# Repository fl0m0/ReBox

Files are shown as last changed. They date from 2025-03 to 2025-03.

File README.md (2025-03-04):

# ReBox - Programmable Relay Switch Box

I started this project to overcome a few nuisances at my working place. I use a couple of old bench power supplies that are still fine. But every one of those suckers features only a mains power switch. So if you hit this switch, the power supply makes a (surprisingly satisfying) 'brrroomp' sound and all output voltage rails go live. The resulting switching transients are neither particularly nice nor repeatable. Nothing you want to hook up to some electronic device.

Yeah, you can solve this by a simple cable switch, what I did. But then, what to do when you need to switch two supply voltages at the same time? You build another cable switch with a double pole single (DPST) throw switch. And if you've got three supply voltages? Well, this is were this projects starts.

My goals for this new device (unimaginatively called ReBox) to be developed were:

* Capability to switch up to six voltages
* Maximum switching current of 10 A at 30 V per channel
* Relays for switching
* 4 mm banana jacks for in- and outputs
* Programmable switch groups: switches in the same group will switch at the same time instance
* Power is supplied via USB-C connector (increasingly common, much more robust than Micro-USB)
* USB-serial interface for debugging and remote control
* Some fancy RGB-LED stuff

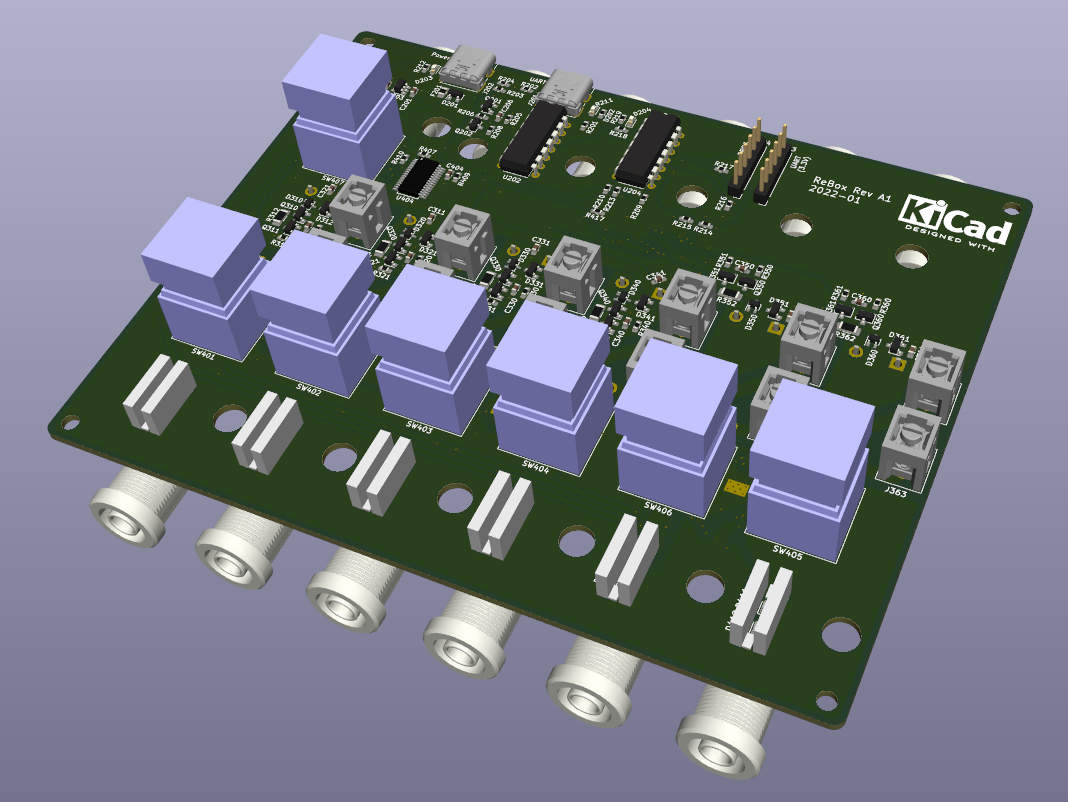
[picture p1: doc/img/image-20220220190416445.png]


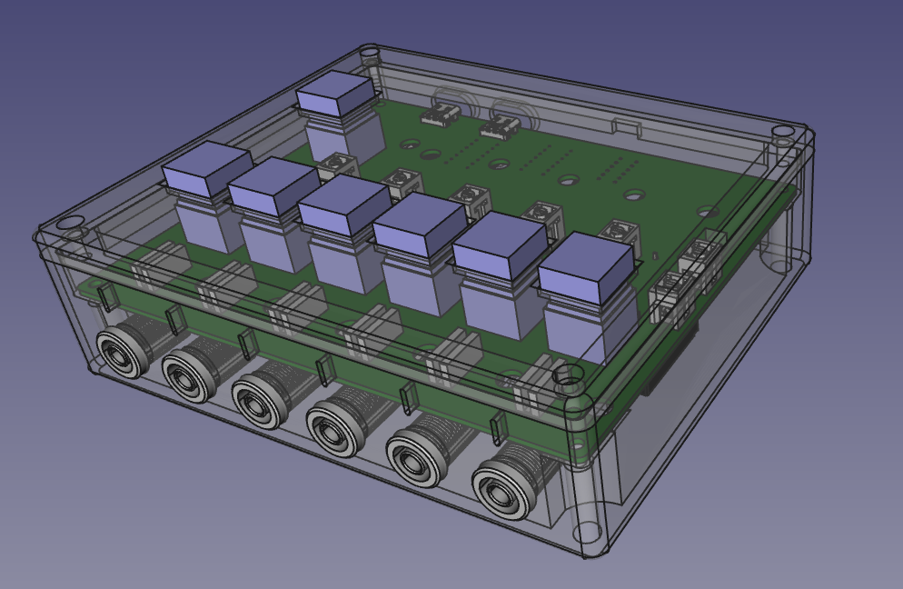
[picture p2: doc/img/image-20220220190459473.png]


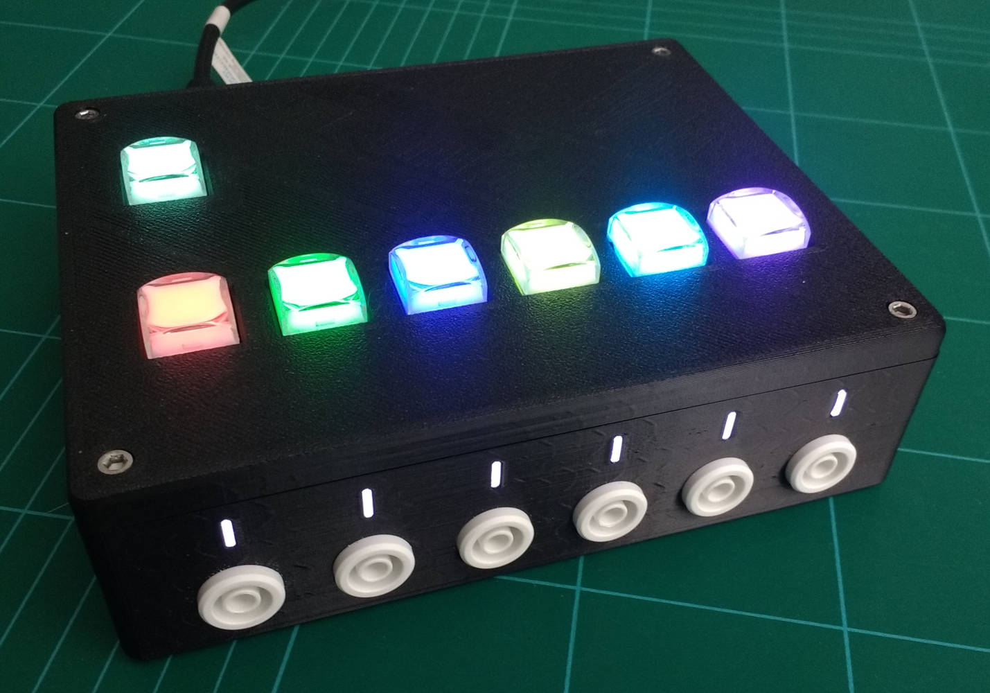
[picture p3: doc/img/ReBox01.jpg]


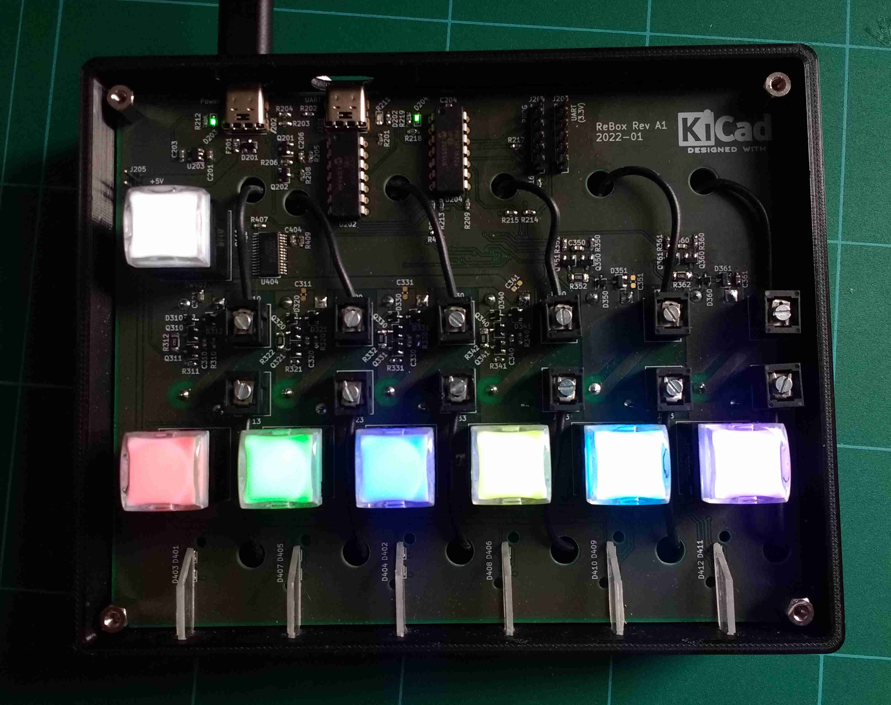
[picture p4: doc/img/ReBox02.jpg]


# Component Choices

## Push Buttons

After intensive searching I went for push buttons I found on AliExpress: [PB06-B-WT-2RGB-N-Y](http://www.honyone.com/en/products/list_32_1.html). They were in stock, cheap an looked quite nice. The downside: they lacked in the documentation department. Those are push buttons with RGB LEDs. Perfect for assigning each push button to a group / color.

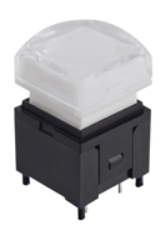
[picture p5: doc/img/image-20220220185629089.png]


## MCU

I was already familiar with the Microchip PIC MCUs. So I chose a PIC16. I have only a PICKit 3 Programmer that doesn't feature an integrated UART for debugging. So some kind of external UART is nescessary.

## USB UART

I went for a [MCP2221A](https://www.microchip.com/en-us/product/MCP2221A) as a USB to UART converter after I realized that none of usual FTDI chips were in stock. I also had to go with a big DIP package (same for the MCU).

```mermaid
stateDiagram-v2
state "SYSTEM_Initialize()" as system_init
state "Init IO expander<br>IO config, all realys off" as init_io_ctrl
state "Init LED controllers,<br>all LEDs off" as init_led_ctrl
state "Get push button states" as get_pb_states
 [*] --> init
 state init {
 	[*] --> system_init
 	system_init --> init_io_ctrl
 	init_io_ctrl --> init_led_ctrl
 	init_led_ctrl --> [*]
 }
 init --> super_loop
 state super_loop {
 get_pb_states --> two
 }
 super_loop --> super_loop: tmr0_trigger = 1

```

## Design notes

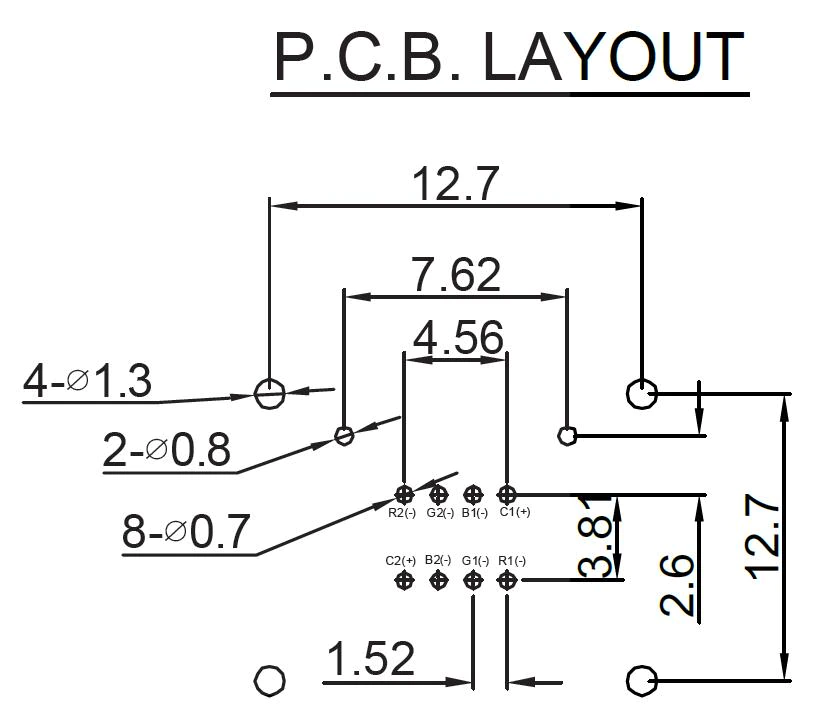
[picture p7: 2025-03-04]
doc/datasheets/switch/Hdd3ee6b0d6b543dcbb89db70b7351162p.webp

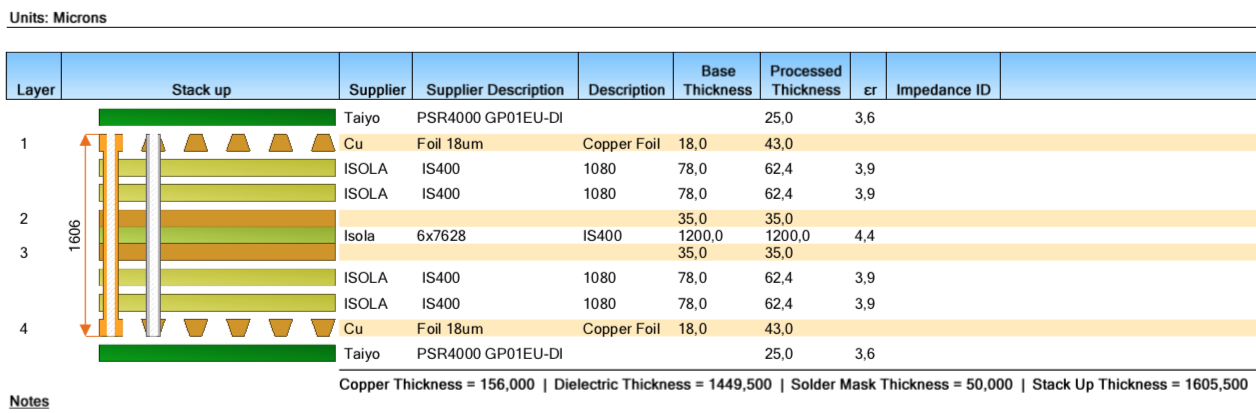
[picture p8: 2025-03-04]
doc/datasheets/PCB/4-layerstackup-275ac8cc.png

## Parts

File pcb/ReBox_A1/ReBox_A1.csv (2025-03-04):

Bestellstatus | Reference | Quantity | Value | Footprint | Datasheet | Manufacturer | SPN | Supplier | Info | Pretty Value | Pretty Value 1 | Pretty Value 2 | Supplier Part Number | DNP | Supplier 1 | Prettl Value
Vorhanden | C201 C205 C401 C402 C403 C404 | 6 | 100nF,50V,X7R,0603 | Capacitor_SMD:C_0603_1608Metric_Pad1.08x0.95mm_HandSolder | ~ |  |  |  |  |  | 100nF, 50V | X7R, 0603
Ersatz 1UF 35V X7R 0603 | C202 C203 | 2 | 1uF,16V,X7R,0603 | Capacitor_SMD:C_0603_1608Metric_Pad1.08x0.95mm_HandSolder | ~ |  |  |  |  |  | 1μF, 16V | X7R, 0603
Ersatz CC0603KRX7R8BB474 | C204 C301 C302 C303 C304 C305 C306 | 7 | 470nF,50V,X7R,0805 | Capacitor_SMD:C_0805_2012Metric_Pad1.18x1.45mm_HandSolder | ~ |  |  |  |  |  | 470nF, 50V | X7R, 0805
OK | D201 | 1 | 824021 | Package_TO_SOT_SMD_User:SOT-23_Handsoldering | https://www.we-online.com/catalog/datasheet/824021.pdf | Wurth Elektronik | 732-4468-1-ND | Digi-Key
Ersatz LTST-C191TGKT | D202 D203 D204 | 3 | 150060GS75000 | LED_SMD:LED_0603_1608Metric_Pad1.05x0.95mm_HandSolder | https://www.we-online.com/katalog/datasheet/150060GS75000.pdf | Wurth Elektronik | 732-4971-1-ND | Digi-Key | Green
OK | D302 D304 D306 D308 D310 D312 | 6 | BZX84C12-7-F | Diode_SMD_User:D_SOT-23_ANK_Handsoldering | https://www.diodes.com/assets/Datasheets/ds18001.pdf | Diodes Incorporated | BZX84C12-FDICT-ND | Digi-Key
OK | D301 D303 D305 D307 D309 D311 | 6 | BAT54W,xxx | Package_TO_SOT_SMD_User:SOT-323_SC-70_Handsoldering | https://assets.nexperia.com/documents/data-sheet/BAT54W_SER.pdf | Nexperia | 1727-3570-1-ND | Digi-Key
OK | D401 D402 D403 D404 D405 D406 D407 D408 D409 D410 D411 D412 | 12 | IN-S63AT5UW | LED_SMD_User:LED_0603_1608Metric_Low_Profile | http://www.inolux-corp.com/datasheet/SMDLED/Mono%20Color%20Top%20View/IN-S63AT%20Series_V1.1.pdf | Inolux | 1830-1063-1-ND | Digi-Key | White
OK | F201 | 1 | 0805L110SLxx | Fuse:Fuse_0805_2012Metric_Pad1.15x1.40mm_HandSolder | https://www.littelfuse.com/media?itemid=2d55f293-08b4-4e1c-af6d-dbdeccdec69c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 | Littelfuse | F3365CT-ND | Digi-Key | 1.1 A, 6V |  |  |  | F3365CT-ND
OK | J201 J202 | 2 | 2137160001 | Connector_User:USB_C_Receptacle_Molex_2137160001 | https://www.molex.com/molex/products/part-detail/io_connectors/2137160001 | Molex | 900-2137160001CT-ND | Digi-Key
OK | J203 J204 | 2 | 77311-118-06LF | Connector_PinHeader_2.54mm:PinHeader_1x06_P2.54mm_Vertical | https://cdn.amphenol-icc.com/media/wysiwyg/files/drawing/77311.pdf | Amphenol | 609-5682-ND | Digi-Key |  |  |  |  |  | DNP
Evtl. Vertikal? | J301 J302 J303 J304 J305 J306 J307 J308 J309 J310 J311 J312 | 12 | 928814-1 | Connector_User:TE_928814-1_PCB_Tab_Quick_Disconnect_4.75x0.81mm_P5.08mm_Horizontal | https://www.te.com/commerce/DocumentDelivery/DDEController?Action=showdoc | TE | A106570-ND | Digi-Key | PCB Tab
Ersatz BSS138AKA | Q201 Q202 | 2 | BSS138BK | Package_TO_SOT_SMD_User:SOT-23_Handsoldering | https://assets.nexperia.com/documents/data-sheet/BSS138BK.pdf | Nexperia | 1727-1141-1-ND | Digi-Key
OK | Q301 Q302 Q303 Q304 Q305 Q306 Q307 Q308 Q309 Q310 Q311 Q312 | 12 | BSH103,xxx | Package_TO_SOT_SMD_User:SOT-23_HandSoldering | https://assets.nexperia.com/documents/data-sheet/BSH103.pdf | Nexperia | 1727-4319-1-ND | Digi-Key
Vorhanden | R202 R203 R217 R218 R219 | 5 | 2.2k,0603 | Resistor_SMD:R_0603_1608Metric_Pad1.05x0.95mm_HandSolder | ~ |  |  |  | 1%, 0,1W | 2.2k, 0603
Vorhanden | R201 R204 R205 R206 R207 R212 R215 R301 R306 R311 R312 R317 R318 R401 R402 R405 R407 | 17 | 10k,0603 | Resistor_SMD:R_0603_1608Metric_Pad1.05x0.95mm_HandSolder | ~ |  |  |  | 1%, 0,1W | 10k, 0603
OK | R208 R209 R214 R216 | 4 | 5.1k,0603 | Resistor_SMD:R_0603_1608Metric_Pad1.05x0.95mm_HandSolder | ~ |  |  |  | 1%, 0,1W | 5.1k, 0603
Vorhanden | R210 R211 | 2 | 0R,0603 | Resistor_SMD:R_0603_1608Metric_Pad1.05x0.95mm_HandSolder | ~ |  |  |  |  |  | 0R, 0603 | 1%, 0,1W
Vorhanden | R213 | 1 | 0R,0603 | Resistor_SMD:R_0603_1608Metric_Pad0.98x0.95mm_HandSolder | ~ |  |  |  |  |  | 0R, 0603 | 1%, 0,1W |  | DNP
OK | R302 R303 R307 R308 R313 R314 | 6 | 330k,0603 | Resistor_SMD:R_0603_1608Metric_Pad1.05x0.95mm_HandSolder | ~ |  |  |  | 1%, 0,1W | 330k, 0603
OK | R304 R305 R309 R310 R315 R316 | 6 | 47R,1206 | Resistor_SMD:R_1206_3216Metric_Pad1.42x1.75mm_HandSolder | ~ |  |  |  | 1%, 0,5W | 47R, 1206
OK | R403 R404 R406 R408 | 4 | 3k,0603 | Resistor_SMD:R_0603_1608Metric_Pad1.05x0.95mm_HandSolder | ~ |  |  |  | 1%, 0,1W | 3k, 0603
Vorhanden | R409 R410 | 2 | 100k,0603 | Resistor_SMD:R_0603_1608Metric_Pad0.98x0.95mm_HandSolder | ~ |  |  |  |  |  | 100k, 0603 | 1%, 0,1W
OK | RL301 RL302 RL303 RL304 RL305 RL306 | 6 | JW1aFSN-DC5V-F | Relay_THT:Relay_SPST_Panasonic_JW1_FormA | http://www3.panasonic.biz/ac/e_download/control/relay/power/catalog/mech_eng_jw.pdf?via=ok | Panasonic | 255-3442-ND |  |  |  |  |  |  |  | Digi-Key
OK | SW401 SW402 SW403 SW404 SW405 SW406 SW407 | 7 | PB06-B-WT-2RGB-N-Y | Switch_User:PB06-B-Wx-2RGB-x-x | http://www.honyone.com/en/products/show_243.html | HONYONNE
OK | U201 | 1 | PCA9535DWR | Package_SO:SOIC-24W_7.5x15.4mm_P1.27mm | https://www.ti.com/lit/ds/symlink/pca9535.pdf | Texas Instruments | 296-20950-1-ND | Digi-Key
Ersatz PIC16F18326-I/P | U202 | 1 | PIC16F18326-ISL | Package_SO:SOIC-14_3.9x8.7mm_P1.27mm | https://ww1.microchip.com/downloads/en/DeviceDoc/40001839E.pdf |  | PIC16F18326-I/SL-ND | Digi-Key
Vorhanden | U203 | 1 | XC6210B332MR | Package_TO_SOT_SMD:SOT-23-5 | https://www.torexsemi.com/file/xc6210/XC6210.pdf
OK | U204 | 1 | MCP2221AxP | Package_DIP:DIP-14_W7.62mm | http://ww1.microchip.com/downloads/en/DeviceDoc/20005565B.pdf | Microchip | MCP2221A-I/P-ND | Digi-Key
OK | U205 | 1 | 824001 | Package_TO_SOT_SMD:SOT-23-6_Handsoldering | https://www.we-online.com/catalog/datasheet/824001.pdf | Wuerth Elektronik | 732-4464-1-ND | Digi-Key
OK | U401 U402 U403 U404 | 4 | PCA9955TW | Package_SO_User:HTSSOP28_EP | https://www.nxp.com/docs/en/data-sheet/PCA9955B.pdf | NXP | 568-12427-1-ND | Digi-Key

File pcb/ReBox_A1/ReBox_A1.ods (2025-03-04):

Bestellstatus | Reference | Quantity | Value | Manufacturer | SPN | Supplier | Info | Pretty Value | Pretty Value 1 | Pretty Value 2 | Supplier Part Number | DNP | Supplier 1 | Prettl Value
Vorhanden | C201 C205 C401 C402 C403 C404 | 6 | 100nF,50V,X7R,0603 |  |  |  |  |  | 100nF, 50V | X7R, 0603
Ersatz 1UF 35V X7R 0603 | C202 C203 | 2 | 1uF,16V,X7R,0603 |  |  |  |  |  | 1μF, 16V | X7R, 0603
Ersatz CC0603KRX7R8BB474 | C204 C301 C302 C303 C304 C305 C306 | 7 | 470nF,50V,X7R,0805 |  |  |  |  |  | 470nF, 50V | X7R, 0805
OK | D201 | 1 | 824021 | Wurth Elektronik | 732-4468-1-ND | Digi-Key
Ersatz LTST-C191TGKT | D202 D203 D204 | 3 | 150060GS75000 | Wurth Elektronik | 732-4971-1-ND | Digi-Key | Green
OK | D302 D304 D306 D308 D310 D312 | 6 | BZX84C12-7-F | Diodes Incorporated | BZX84C12-FDICT-ND | Digi-Key
OK | D301 D303 D305 D307 D309 D311 | 6 | BAT54W,xxx | Nexperia | 1727-3570-1-ND | Digi-Key
OK | D401 D402 D403 D404 D405 D406 D407 D408 D409 D410 D411 D412 | 12 | IN-S63AT5UW | Inolux | 1830-1063-1-ND | Digi-Key | White
OK | F201 | 1 | 0805L110SLxx | Littelfuse | F3365CT-ND | Digi-Key | 1.1 A, 6V |  |  |  | F3365CT-ND
OK | J201 J202 | 2 | 2137160001 | Molex | 900-2137160001CT-ND | Digi-Key
OK | J203 J204 | 2 | 77311-118-06LF | Amphenol | 609-5682-ND | Digi-Key |  |  |  |  |  | DNP
Entfällt | J301 J302 J303 J304 J305 J306 J307 J308 J309 J310 J311 J312 | 12 | 928814-1 | TE | A106570-ND | Digi-Key | PCB Tab
Ersatz BSS138AKA | Q201 Q202 | 2 | BSS138BK | Nexperia | 1727-1141-1-ND | Digi-Key
OK | Q301 Q302 Q303 Q304 Q305 Q306 Q307 Q308 Q309 Q310 Q311 Q312 | 12 | BSH103,xxx | Nexperia | 1727-4319-1-ND | Digi-Key
Vorhanden | R202 R203 R217 R218 R219 | 5 | 2.2k,0603 |  |  |  | 1%, 0,1W | 2.2k, 0603
Vorhanden | R201 R204 R205 R206 R207 R212 R215 R301 R306 R311 R312 R317 R318 R401 R402 R405 R407 | 17 | 10k,0603 |  |  |  | 1%, 0,1W | 10k, 0603
OK | R208 R209 R214 R216 | 4 | 5.1k,0603 |  |  |  | 1%, 0,1W | 5.1k, 0603
Vorhanden | R210 R211 | 2 | 0R,0603 |  |  |  |  |  | 0R, 0603 | 1%, 0,1W
Vorhanden | R213 | 1 | 0R,0603 |  |  |  |  |  | 0R, 0603 | 1%, 0,1W |  | DNP
OK | R302 R303 R307 R308 R313 R314 | 6 | 330k,0603 |  |  |  | 1%, 0,1W | 330k, 0603
OK | R304 R305 R309 R310 R315 R316 | 6 | 47R,1206 |  |  |  | 1%, 0,5W | 47R, 1206
OK | R403 R404 R406 R408 | 4 | 3k,0603 |  |  |  | 1%, 0,1W | 3k, 0603
Vorhanden | R409 R410 | 2 | 100k,0603 |  |  |  |  |  | 100k, 0603 | 1%, 0,1W
OK | RL301 RL302 RL303 RL304 RL305 RL306 | 6 | JW1aFSN-DC5V-F | Panasonic | 255-3442-ND |  |  |  |  |  |  |  | Digi-Key
OK | SW401 SW402 SW403 SW404 SW405 SW406 SW407 | 7 | PB06-B-WT-2RGB-N-Y | HONYONNE
OK | U201 | 1 | PCA9535DWR | Texas Instruments | 296-20950-1-ND | Digi-Key
Ersatz PIC16F18326-I/P | U202 | 1 | PIC16F18326-ISL |  | PIC16F18326-I/SL-ND | Digi-Key
Vorhanden | U203 | 1 | XC6210B332MR
OK | U204 | 1 | MCP2221AxP | Microchip | MCP2221A-I/P-ND | Digi-Key
OK | U205 | 1 | 824001 | Wuerth Elektronik | 732-4464-1-ND | Digi-Key
OK | U401 U402 U403 U404 | 4 | PCA9955TW | NXP | 568-12427-1-ND | Digi-Key

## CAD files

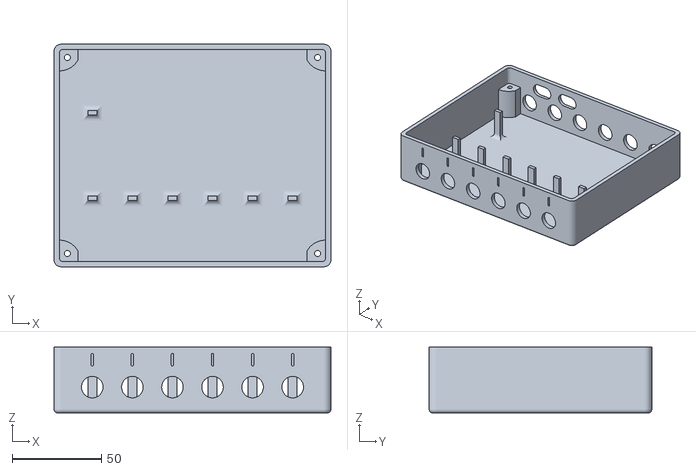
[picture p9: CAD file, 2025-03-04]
mechanical/case_base.stl
155.5 x 125.0 x 37.0

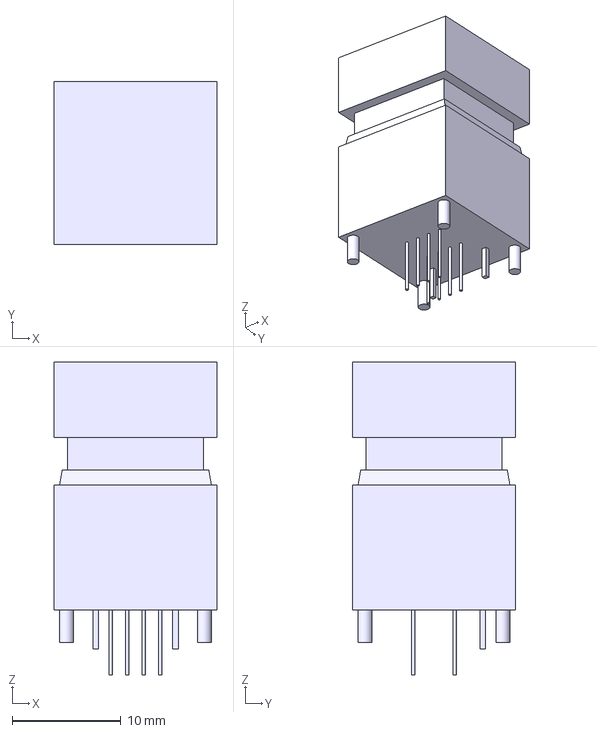
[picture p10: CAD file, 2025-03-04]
mechanical/PB06-B-Wx-2RGB-x-x.step
15.0 x 15.0 x 28.9 mm

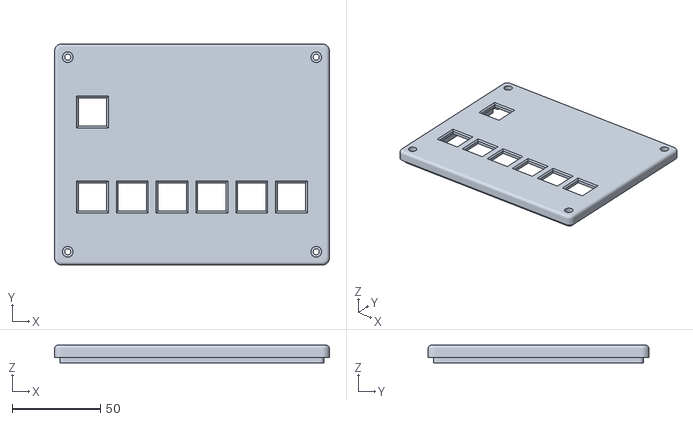
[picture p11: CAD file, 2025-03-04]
mechanical/case_lid.stl
155.5 x 125.0 x 10.0

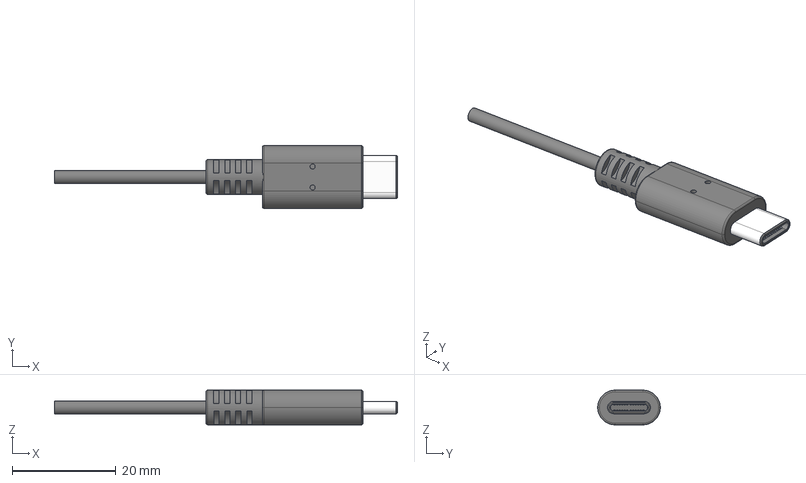
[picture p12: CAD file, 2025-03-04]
mechanical/Official Pi 4 USB-C charger plug.step
66.2 x 12.1 x 6.70 mm
USB Plug
Inner
Outer

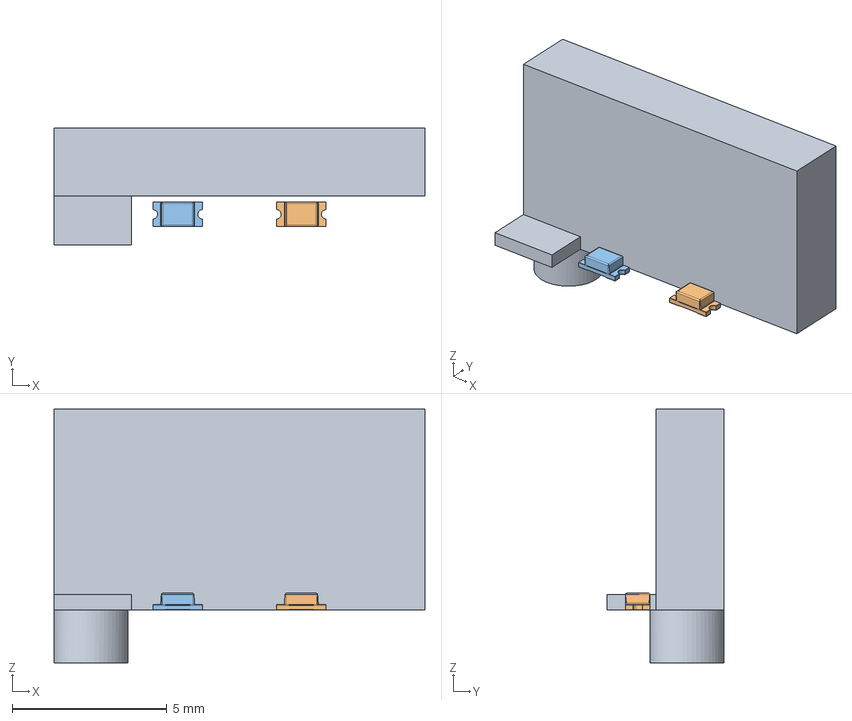
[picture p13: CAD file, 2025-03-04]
mechanical/Light_Pipe_Mount.FCStd
12.0 x 3.80 x 8.20 mm
LED1
LED2

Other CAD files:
mechanical/AI3M_case_base.3mf
mechanical/AI3M_case_lid.3mf
mechanical/Light_Pipe_Mount.stl
mechanical/PB06-B-Wx-2RGB-x-x.FCStd

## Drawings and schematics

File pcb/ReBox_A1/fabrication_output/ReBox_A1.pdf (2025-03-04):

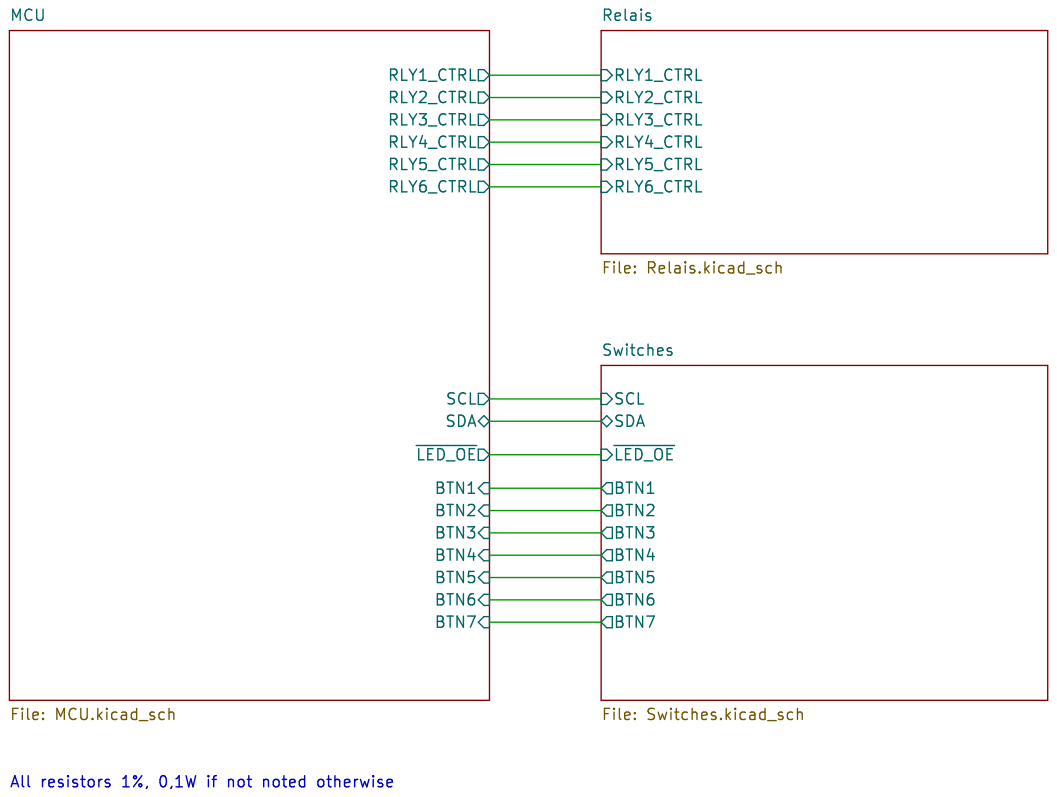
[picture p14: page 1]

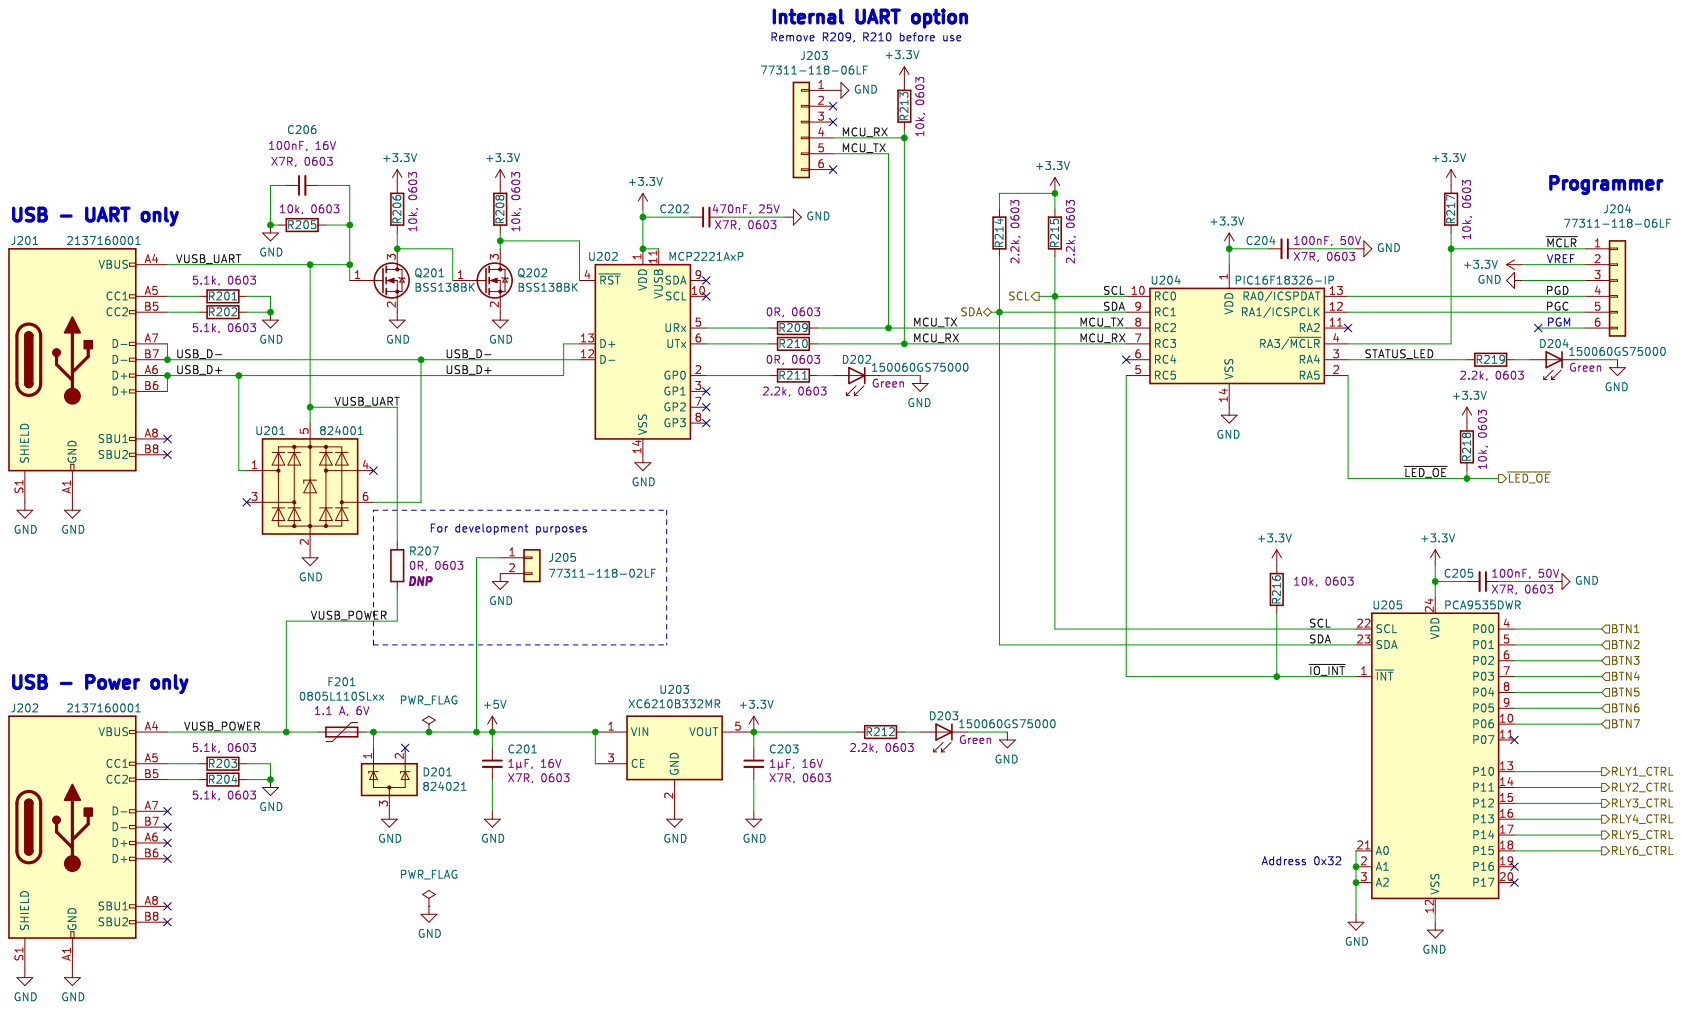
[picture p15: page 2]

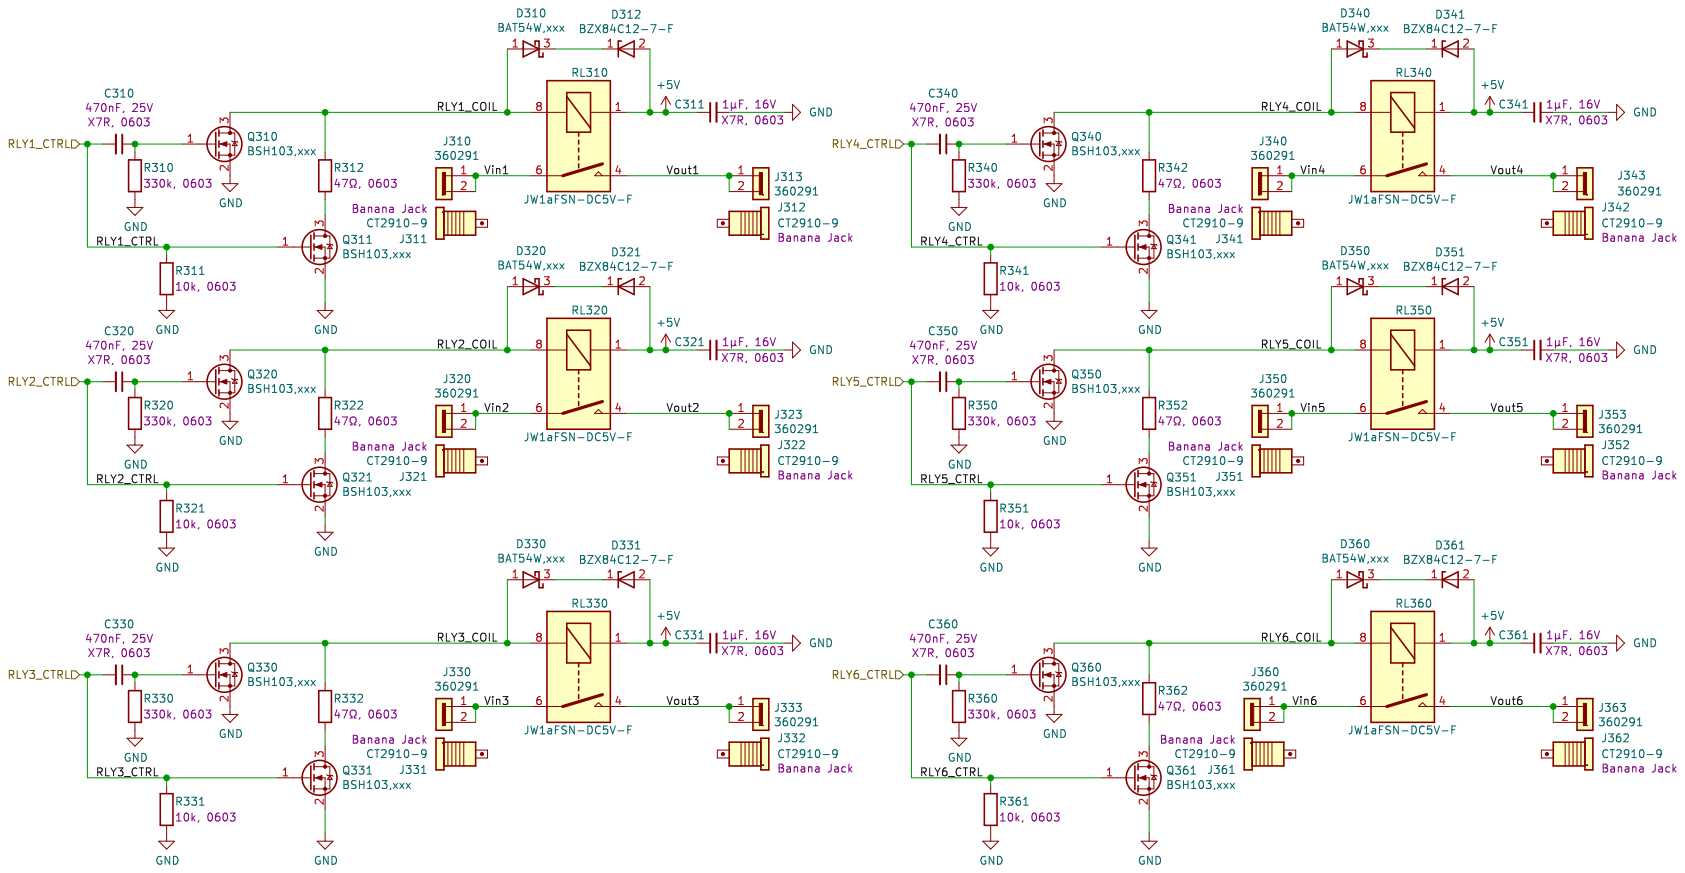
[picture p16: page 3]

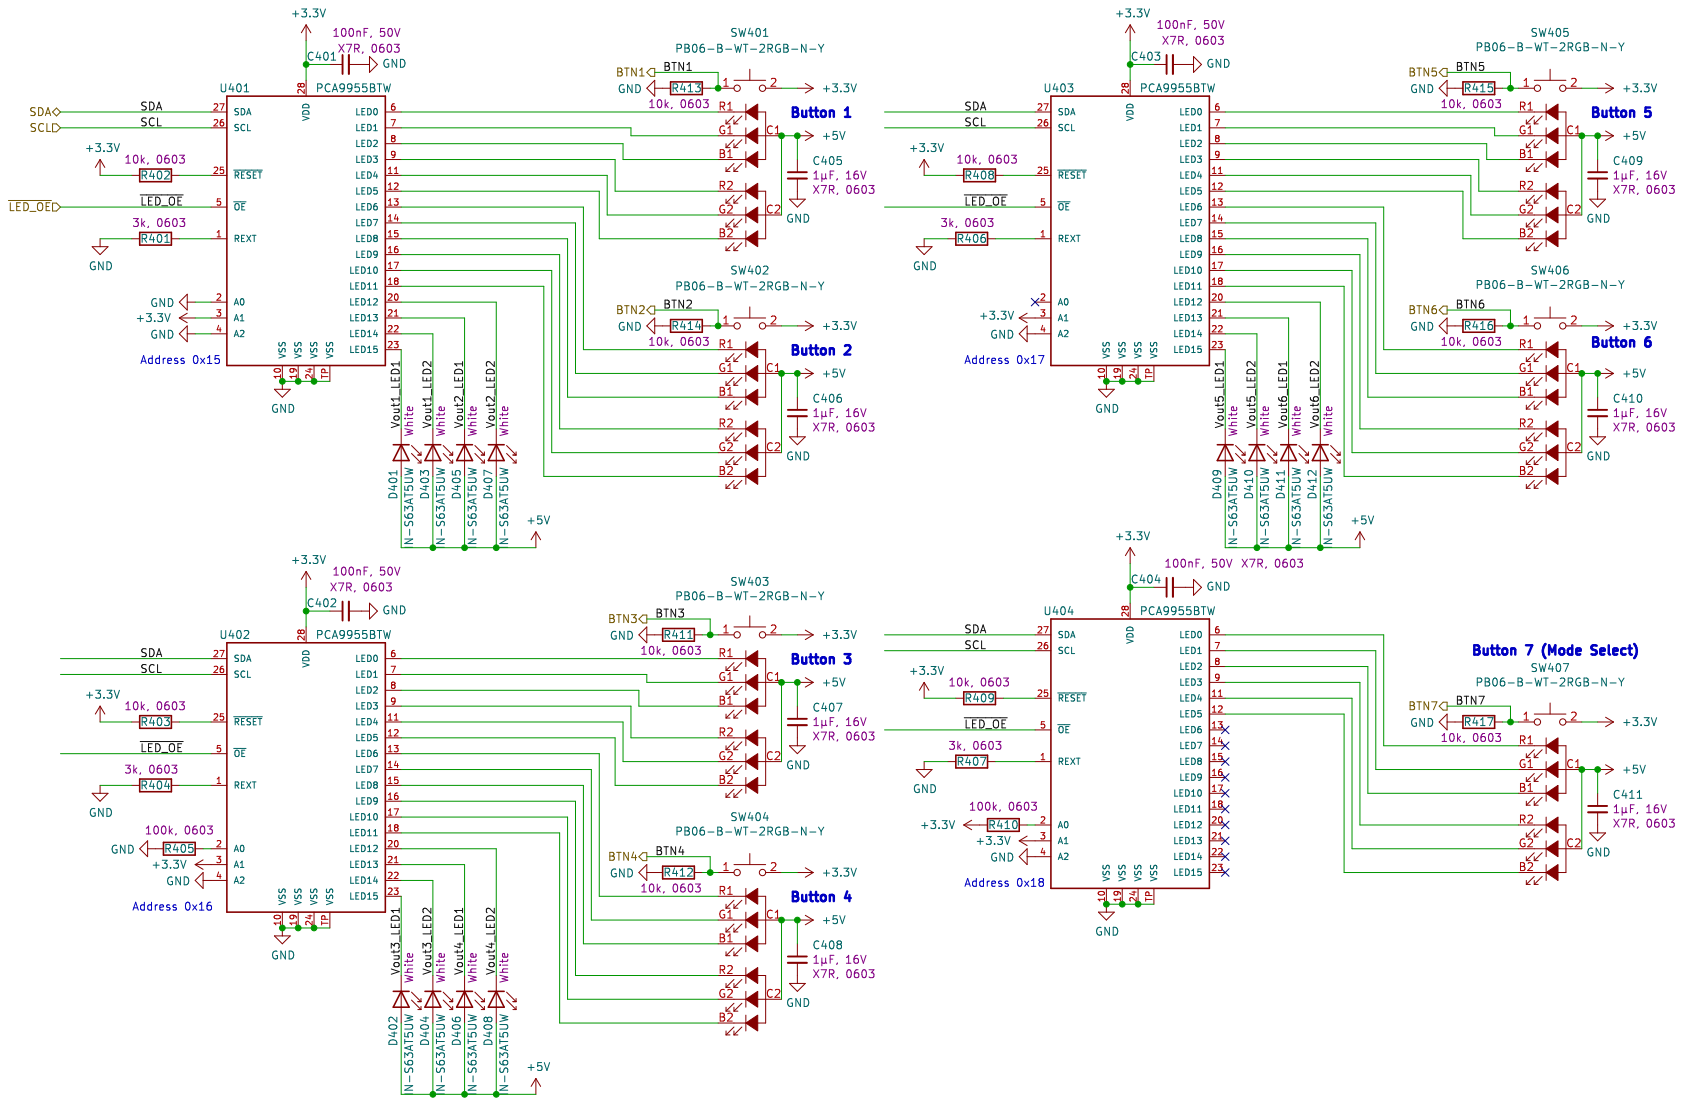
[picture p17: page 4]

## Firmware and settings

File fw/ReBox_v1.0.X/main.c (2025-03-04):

/**
  Generated Main Source File

  Company:
    Microchip Technology Inc.

  File Name:
    main.c

  Summary:
    This is the main file generated using PIC10 / PIC12 / PIC16 / PIC18 MCUs

  Description:
    This header file provides implementations for driver APIs for all modules selected in the GUI.
    Generation Information :
        Product Revision  :  PIC10 / PIC12 / PIC16 / PIC18 MCUs - 1.81.7
        Device            :  PIC16F18326
        Driver Version    :  2.00
*/

/*
    (c) 2018 Microchip Technology Inc. and its subsidiaries. 
    
    Subject to your compliance with these terms, you may use Microchip software and any 
    derivatives exclusively with Microchip products. It is your responsibility to comply with third party 
    license terms applicable to your use of third party software (including open source software) that 
    may accompany Microchip software.
    
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
    IN NO EVENT WILL MICROCHIP BE LIABLE FOR ANY INDIRECT, SPECIAL, PUNITIVE, 
    INCIDENTAL OR CONSEQUENTIAL LOSS, DAMAGE, COST OR EXPENSE OF ANY KIND 
    WHATSOEVER RELATED TO THE SOFTWARE, HOWEVER CAUSED, EVEN IF MICROCHIP 
    HAS BEEN ADVISED OF THE POSSIBILITY OR THE DAMAGES ARE FORESEEABLE. TO 
    THE FULLEST EXTENT ALLOWED BY LAW, MICROCHIP'S TOTAL LIABILITY ON ALL 
    CLAIMS IN ANY WAY RELATED TO THIS SOFTWARE WILL NOT EXCEED THE AMOUNT 
    OF FEES, IF ANY, THAT YOU HAVE PAID DIRECTLY TO MICROCHIP FOR THIS 
    SOFTWARE.
*/

#include "mcc_generated_files/mcc.h"
#include "rebox.h"
#include "i2c.h"
#include "mcc_generated_files/examples/i2c1_master_example.h"

// Global variables
// Color definitions
uint8_t COLOR_RED[3]    = {0xC0,0x00,0x00};
uint8_t COLOR_GREEN[3]  = {0x00,0x80,0x00};
uint8_t COLOR_BLUE[3]   = {0x00,0x00,0xFF};
uint8_t COLOR_YELLOW[3] = {0xD0,0x80,0x00};
uint8_t COLOR_CYAN[3]   = {0x00,0xC0,0xFF};
uint8_t COLOR_VIOLET[3] = {0xC0,0x00,0xFF};
uint8_t COLOR_WHITE[3]  = {0xFF,0x60,0x40};
uint8_t COLOR_OFF[3]    = {0x00,0x00,0x00};
uint8_t COLORS[21]      = {0xC0,0x00,0x00,  // red
                           0x00,0x80,0x00,  // green
                           0x00,0x00,0xFF,  // blue
                           0xD0,0x80,0x00,  // yellow
                           0x00,0xC0,0xFF,  // cyan
                           0xC0,0x00,0xFF,  // violet
                           0xFF,0x60,0x40}; // white

// Timer0: Used for detection of long (2 s) push button presses and some other
//         time delays.
// Timer2: Used for Super Loop, sets tmr0_trigger, 64 ms


/*
                         Main application
 */
void main(void)
{
    operating_mode_t operating_mode = STARTUP;
    // I2C dadresses
    i2c1_address_t led_ctrl0_addr = LED_CTRL0_ADDR;
    i2c1_address_t led_ctrl1_addr = LED_CTRL1_ADDR;
    i2c1_address_t led_ctrl2_addr = LED_CTRL2_ADDR;
    i2c1_address_t led_ctrl3_addr = LED_CTRL3_ADDR;
    i2c1_address_t io_ctrl_addr = IO_CTRL_ADDR;
    uint8_t status_led_state = 0; // Green status LED on PCB, flashes in super loop, 0 = off
    uint8_t pb_states = 0x00; // 0 for pressed, bitwise
    uint8_t pb_rising_edges = 0x00; // 1 for rising edge, bitwise
    uint8_t pb7_long_press = 0;
    uint8_t relay_states = 0x00; // 0 = relay open
    uint8_t relay_states_old = 0x00;
    
    // Group assignment for PBs 1 to PB_GROUPS
    uint8_t pb_groups[PB_GROUPS] = {0, 1, 2, 3, 4, 5};
    uint8_t pb_group_masks[PB_GROUPS] = {0x01,0x02,0x04,0x08,0x10,0x20};

    // initialize the device
    SYSTEM_Initialize();

    // When using interrupts, you need to set the Global and Peripheral Interrupt Enable bits
    // Use the following macros to:

    // Enable the Global Interrupts
    // INTERRUPT_GlobalInterruptEnable();

    // Enable the Peripheral Interrupts
    // INTERRUPT_PeripheralInterruptEnable();

    // Disable the Global Interrupts
    //INTERRUPT_GlobalInterruptDisable();

    // Disable the Peripheral Interrupts
    //INTERRUPT_PeripheralInterruptDisable();
    
    // Configure IO expander in/out pins, initial states
    io_ctrl_cfg(io_ctrl_addr, IO_CTRL_CFG_REGS, IO_CTRL_OUT_REGS);
     // Init LED controllers (current value, pwm off)
    PCA9955B_init(led_ctrl0_addr);
    PCA9955B_init(led_ctrl1_addr);
    PCA9955B_init(led_ctrl2_addr);
    PCA9955B_init(led_ctrl3_addr);
    PCA9955B_gradation_init(led_ctrl3_addr);
    // Initial PB LED colors
    set_pb_color_by_group(pb_groups); // For PBs 1 to 6
    set_pb_color(CH7_LED, COLOR_WHITE); // For PB 7
    LED_OE_N = 0; // LED controller global enable signal
    // Startup animation
    run_startup_animation(0x0D); // 13 cycles
    boot_msg();
    TMR0_StopTimer();
    TMR0_Reload(TMR0_INIT_VAL);
    PIR0bits.TMR0IF = 0;
    // Super loop
    while (1)
    {
        // Periodic trigger from TRM2
        if (TMR2_HasOverflowOccured())
        {
            // Status LED blinki
            STATUS_LED = status_led_state;
            status_led_state = ~status_led_state;
            
            // Get push button states (1 means pressed, bits 0 to 6 = PB 1 to 7)
            pb_states = get_pb_states(io_ctrl_addr);
            pb_rising_edges = pb_edge_detect(pb_states);
            pb7_long_press = pb7_long_press_detect(pb_states, pb_rising_edges);
            
            switch (operating_mode)
            {
                case(STARTUP):
                    operating_mode = NORMAL;
                    break;

                case(NORMAL):
                    // PB7 always opens all realays
                    if (pb7_long_press > 0)
                    {
                        printf("PB7 pressed\r\n");
                        relay_states = 0x00;
                        set_relays(io_ctrl_addr, relay_states);
                    }
                    
                    // PB7 long press switches to programming mode
                    if (pb7_long_press == 2)
                    {
                        printf("Entering programming mode\r\n");
                        operating_mode = PROGRAMMING;
                    }
                    
                    // PBs 1 to 6 are switching the relays
                    if (pb_rising_edges > 0)
                    {
                        // XORing, example:
                        // 1 0 0 1 1 1 relay_states
                        // 0 1 0 1 0 0 rising_edges
                        // ----------- XOR
                        // 1 1 0 0 1 1
                        relay_states = set_relays_by_group(io_ctrl_addr, relay_states, pb_rising_edges, pb_groups, pb_group_masks);
                    }
                    
                    if ((relay_states > 0x00) && (relay_states_old == 0x00))
                    {
                        PCA9955B_gradation_enable(led_ctrl3_addr);
                    }
                    else if ((relay_states == 0x00) && (relay_states_old > 0x00))
                    {
                        PCA9955B_gradation_disable(led_ctrl3_addr);
                    }
                    relay_states_old = relay_states;
                    break;

                case(PROGRAMMING):
                    pb7_led_flash();
                    // PB7 press returns to normal programming mode
                    if (pb7_long_press > 0)
                    {
                        printf("Entering normal mode\r\n");
                        operating_mode = NORMAL;
                        calculate_pb_group_masks(pb_groups, pb_group_masks); // Needed for relay control
                        set_pb_color(CH7_LED, COLOR_WHITE); // Reset after flashing
                    }
                    if (pb_rising_edges > 0)
                    {
                        set_pb_groups(pb_groups, pb_rising_edges);
                        set_pb_color_by_group(pb_groups);
                    }
                    break;
            }
        }

    }
}

void boot_msg()
{
    printf("\r\n---------------------------------------------\r\n");
    printf("                ReBox Rev. A1                \r\n");
    printf("---------------------------------------------\r\n");
    printf("FW version: 0.1, build date 2022-20-02\r\n");
}

void PCA9955B_init(i2c1_address_t addr)
{
    // Global current & PWM, overwrites group settings
    I2C1_Write1ByteRegister(addr, PCA9955B_ADDR_MAP.PWMALL, 0x00);
    I2C1_Write1ByteRegister(addr, PCA9955B_ADDR_MAP.IREFALL, LED_CTRL_IREF);
}

void PCA9955B_gradation_init(i2c1_address_t addr)
{
    // Gradation control:
    // Ramp up enables, ramp down enabled, ramp rate value 0
    I2C1_Write1ByteRegister(addr, PCA9955B_ADDR_MAP.RAMP_RATE_GRP0, 0xC0);
    I2C1_Write1ByteRegister(addr, PCA9955B_ADDR_MAP.RAMP_RATE_GRP1, 0xC0);
    I2C1_Write1ByteRegister(addr, PCA9955B_ADDR_MAP.RAMP_RATE_GRP2, 0xC0);
    // 2*8ms step time
    I2C1_Write1ByteRegister(addr, PCA9955B_ADDR_MAP.STEP_TIME_GRP0, 0x41);
    I2C1_Write1ByteRegister(addr, PCA9955B_ADDR_MAP.STEP_TIME_GRP1, 0x41);
    I2C1_Write1ByteRegister(addr, PCA9955B_ADDR_MAP.STEP_TIME_GRP2, 0x41);
    // Hold ON enable, Hold OFF enable, different Hold OFF times
    I2C1_Write1ByteRegister(addr, PCA9955B_ADDR_MAP.HOLD_CNTL_GRP0, 0x80);
    I2C1_Write1ByteRegister(addr, PCA9955B_ADDR_MAP.HOLD_CNTL_GRP1, 0x88);
    I2C1_Write1ByteRegister(addr, PCA9955B_ADDR_MAP.HOLD_CNTL_GRP2, 0x90);
    I2C1_Write1ByteRegister(addr, PCA9955B_ADDR_MAP.IREF_GRP0, LED_CTRL_IREF); // independant from IREFALL
    I2C1_Write1ByteRegister(addr, PCA9955B_ADDR_MAP.IREF_GRP1, LED_CTRL_IREF);
    I2C1_Write1ByteRegister(addr, PCA9955B_ADDR_MAP.IREF_GRP2, LED_CTRL_IREF);
    // Enable gradiation mode for LEDs 0 to 5
//    I2C1_Write1ByteRegister(addr, PCA9955B_ADDR_MAP.GRAD_MODE_SEL0, 0x3F);
//    I2C1_Write1ByteRegister(addr, PCA9955B_ADDR_MAP.GRAD_MODE_SEL1, 0x00);
    // Assign all LEDs to gradiation groups
    I2C1_Write1ByteRegister(addr, PCA9955B_ADDR_MAP.GRAD_GRP_SEL0, 0x09);
    I2C1_Write1ByteRegister(addr, PCA9955B_ADDR_MAP.GRAD_GRP_SEL1, 0x12);
    I2C1_Write1ByteRegister(addr, PCA9955B_ADDR_MAP.GRAD_GRP_SEL2, 0x24);
    I2C1_Write1ByteRegister(addr, PCA9955B_ADDR_MAP.GRAD_GRP_SEL3, 0x00);
}

void PCA9955B_gradation_enable(i2c1_address_t addr)
{
    // Enable gradiation mode for LEDs 0 to 5
    I2C1_Write1ByteRegister(addr, PCA9955B_ADDR_MAP.GRAD_MODE_SEL0, 0x3F);
    // Start group 0
    I2C1_Write1ByteRegister(addr, PCA9955B_ADDR_MAP.GRAD_CNTL, 0x3F);
}

void PCA9955B_gradation_disable(i2c1_address_t addr)
{
    // Disable gradiation mode for LEDs 0 to 5
    I2C1_Write1ByteRegister(addr, PCA9955B_ADDR_MAP.GRAD_MODE_SEL0, 0x00);
    // Stop group 0
    I2C1_Write1ByteRegister(addr, PCA9955B_ADDR_MAP.GRAD_CNTL, 0x00);
}


/**
 * Reads one register 
 * @param i2c1_address_t device_addr
 * @param uint8_t reg_addr
 */
void PCA9955B_read(i2c1_address_t device_addr, uint8_t reg_addr)
{
    uint8_t val = 0x00;
    val = I2C1_Read1ByteRegister(device_addr, reg_addr);
    printf("0x%x -> 0x%x\r\n", reg_addr, val);
}

/**
 * Sets the led colors (RGB) of one push button
 * @param led_addr_t led_addr
 * @param uint8_t *p_color, pointer to array with 3 elements
 */
void set_pb_color(led_addr_t led_addr, uint8_t *p_color)
{
    uint8_t idx = 0;
    // Three colors (RGB) per push button.
    // Two LEDs per push button. Same color on addresses x and x+3.
    for (idx = 0; idx < 3; idx++)
    {
        I2C1_Write1ByteRegister(led_addr.I2C_ADDR, PCA9955B_ADDR_MAP.PWM0+led_addr.PB_LED_R0 + idx, p_color[idx]);
        I2C1_Write1ByteRegister(led_addr.I2C_ADDR, PCA9955B_ADDR_MAP.PWM0+led_addr.PB_LED_R0 + idx + 3, p_color[idx]);
    }
}

/**
 * Sets the indicator LEDs for each channel (relay closed)
 * Accounts for the swapped LEDs: CH1 <=> CH2, CH3 <=> CH4
 * @param relay_states
 */
void set_relay_closed_led(uint8_t relay_states)
{
    // For both LEDs
    for (uint8_t ii = 0; ii < PB_GROUPS; ii++)
    {
        // Bit masks due to another PCB layout mistake :-(
        _set_relay_closed_led_helper(CH1_LED, relay_states & 0x02);
        _set_relay_closed_led_helper(CH2_LED, relay_states & 0x01);
        _set_relay_closed_led_helper(CH3_LED, relay_states & 0x08);
        _set_relay_closed_led_helper(CH4_LED, relay_states & 0x04);
        _set_relay_closed_led_helper(CH5_LED, relay_states & 0x10);
        _set_relay_closed_led_helper(CH6_LED, relay_states & 0x20);
    }
    
}

/**
 * Helper function for set_relay_closed_led
 * @param led_addr
 * @param pwm_val
 */
void _set_relay_closed_led_helper(led_addr_t led_addr, uint8_t pwm_val)
{
    
    uint8_t pwm_local = 0x00;
    if (pwm_val > 0)
    {
        pwm_local = PWR_LED_PWM_ON;
    }
    // For both LEDs
    for (uint8_t ii = 0; ii < 2; ii++)
    {
        I2C1_Write1ByteRegister(led_addr.I2C_ADDR, PCA9955B_ADDR_MAP.PWM0+led_addr.PWR_LED0+ii, pwm_local);
    }
}

/**
 * Sets the PB color according to it's group number
 * @param p_pb_groups
 */
void set_pb_color_by_group(uint8_t *p_pb_groups)
{
    // p_pb_groups points to the first value in the COLOR array
    set_pb_color(CH1_LED, COLORS + p_pb_groups[0]*3);
    set_pb_color(CH2_LED, COLORS + p_pb_groups[1]*3);
    set_pb_color(CH3_LED, COLORS + p_pb_groups[2]*3);
    set_pb_color(CH4_LED, COLORS + p_pb_groups[3]*3);
    set_pb_color(CH5_LED, COLORS + p_pb_groups[4]*3);
    set_pb_color(CH6_LED, COLORS + p_pb_groups[5]*3);
}

/**
 * Cycles push button colors
 * Uses global variables CHx_LED and COLORS, uses TMR0
 * @param uint8_t n_cycles, number of cycles
 */
void run_startup_animation(uint8_t n_cycles)
{
    uint8_t cycle_counter = 0;
    uint8_t color_indices[PB_GROUPS] = {0,3,6,9,12,15};
    uint8_t ii = 0;
    uint8_t tmp = 0;
    TMR0_Reload(0x20);
    TMR0_StartTimer();
    // Cycle loop, one cycle = one color shift
    for (cycle_counter = 0; cycle_counter < n_cycles; cycle_counter++)
    {
        while (~TMR0_HasOverflowOccured())
        {
            NOP();
        }
        PIR0bits.TMR0IF = 0;
        set_pb_color(CH1_LED, COLORS+color_indices[0]);
        set_pb_color(CH2_LED, COLORS+color_indices[1]);
        set_pb_color(CH3_LED, COLORS+color_indices[2]);
        set_pb_color(CH4_LED, COLORS+color_indices[3]);
        set_pb_color(CH5_LED, COLORS+color_indices[4]);
        set_pb_color(CH6_LED, COLORS+color_indices[5]);
        // Cyclic shift of color_indeces
        tmp = color_indices[0];
        for (ii = 0; ii< 5; ii++)
        {
            color_indices[ii] = color_indices[ii+1];
        }
        color_indices[5] = tmp;
    }
    TMR0_StopTimer();
    TMR0_Reload(TMR0_INIT_VAL);
    PIR0bits.TMR0IF = 0;
}

void set_color1(i2c1_address_t addr, uint8_t *p_color)
{
    /*
     red = 0,3
     green = 1,4
     blue = 2,5
     */
    uint8_t color_index = 0;
    for (color_index = 0; color_index < 3; color_index++)
    {
        I2C1_Write1ByteRegister(addr, PCA9955B_ADDR_MAP.PWM0+color_index, p_color[color_index]);
        I2C1_Write1ByteRegister(addr, PCA9955B_ADDR_MAP.PWM0+color_index+3, p_color[color_index]);
    }

}

void set_color2(i2c1_address_t addr, uint8_t *p_color)
{
    /*
     red = 0,3
     green = 1,4
     blue = 2,5
     */
    uint8_t color_index = 0;
    for (color_index = 0; color_index < 3; color_index++)
    {
        I2C1_Write1ByteRegister(addr, PCA9955B_ADDR_MAP.PWM0+color_index, p_color[color_index]);
        I2C1_Write1ByteRegister(addr, PCA9955B_ADDR_MAP.PWM0+color_index+3, p_color[color_index]);
        I2C1_Write1ByteRegister(addr, PCA9955B_ADDR_MAP.PWM6+color_index, p_color[color_index]);
        I2C1_Write1ByteRegister(addr, PCA9955B_ADDR_MAP.PWM6+color_index+3, p_color[color_index]);
    }
    I2C1_Write1ByteRegister(addr, PCA9955B_ADDR_MAP.PWM12, 0x0F);
    I2C1_Write1ByteRegister(addr, PCA9955B_ADDR_MAP.PWM13, 0x0F);
    I2C1_Write1ByteRegister(addr, PCA9955B_ADDR_MAP.PWM14, 0x0F);
    I2C1_Write1ByteRegister(addr, PCA9955B_ADDR_MAP.PWM15, 0x0F);
}

uint8_t get_pb_states(i2c1_address_t addr)
/*
 * Some extra bit manipulations are required, because of swapped PB numbers
 * on the PCB ;-(
 */
{
    uint8_t pb_states_messed_up; // PBs 5 & 6 are swapped (1 based indexing!)
    uint8_t pb_states;
    pb_states_messed_up = I2C1_Read1ByteRegister(addr, PCA9535_CMD.IN_PORT0);
    pb_states = pb_states_messed_up & 0xCF; // Copy states, but without PBs 6 & 7
    // Swapping...
    // Bit:  7 6 5 4 3 2 1 0
    // PB:   - 7 5 6 4 3 2 1
    // Mask: 0 0 1 0 0 0 0 0 (0x20)
    // Mask: 0 0 0 1 0 0 0 0 (0x10)
    // PB 6 on bit pos. 5: left shift
    pb_states |= (pb_states_messed_up & 0x20) >> 1;
    // PB 5 on bit pos. 6: right shift
    pb_states |= (pb_states_messed_up & 0x10) << 1;

    //printf("SW: 0x%x -> 0x%x\r\n", PCA9535_CMD.IN_PORT0, pb_states);
    // relay_status = I2C1_Read1ByteRegister(addr, PCA9535_CMD.IN_PORT1);
    //printf("RLY: 0x%x -> 0x%x\r\n", PCA9535_CMD.IN_PORT1, pb_states);
    return pb_states;

}

uint8_t io_ctrl_cfg(i2c1_address_t addr, uint16_t cfg_reg_pair, uint16_t out_reg_pair)
{
    uint16_t result;
    // Set relay IOs to 0 before configuring them as output
    I2C1_Write2ByteRegister(addr, PCA9535_CMD.OUT_PORT0, out_reg_pair);
    I2C1_Write2ByteRegister(addr, PCA9535_CMD.CFG_PORT0, cfg_reg_pair);
    /* I2C1_Read2ByteRegister returns high byte first!
     * By reading 2 bytes starting at CFG_PORT1 result contains PORT1
     * in the upper byte, PORT0 at the lower byte.
    */
    result = I2C1_Read2ByteRegister(addr, PCA9535_CMD.OUT_PORT1);
    // printf("OUT PORT reg: 0x%x\r\n", result);
    result = I2C1_Read2ByteRegister(addr, PCA9535_CMD.CFG_PORT1);
    // printf("CFG reg: 0x%x\r\n", result);
    
    
    if (result != cfg_reg_pair)
    {
        printf("IO_CTRL_CFG failure!\r\n");
        printf("IO-CFG: Wrote 0x%x, got 0x%x\r\n", cfg_reg_pair, result);
        return 1;
    }
    return 0;
}

void set_relays(i2c1_address_t addr, uint8_t relay_states)
/* 
 * Direct mapping from PB input to relay control:
 * PB pressed = 1 = relay closed
 */
{
    printf("SET RLY: 0x%x\r\n", relay_states | RELAY_MASK);
    // RELAY_MASK sets unused channels to high
    I2C1_Write1ByteRegister(addr, PCA9535_CMD.OUT_PORT1, relay_states | RELAY_MASK);
    set_relay_closed_led(relay_states);
}

uint8_t set_relays_by_group(i2c1_address_t addr, uint8_t relay_states,
        uint8_t pb_rising_edges, uint8_t *p_pb_groups, uint8_t *p_pb_group_masks)
{
    uint8_t grouped_relay_states = 0x00;
    // Going through PB groups and set new relay state by XORing
    for (uint8_t ii = 0; ii < PB_GROUPS; ii++)
    {
        if ((pb_rising_edges & 0x01) == 1)
        {
            // Ugly look-up
            grouped_relay_states |= p_pb_group_masks[p_pb_groups[ii]] ^ relay_states;
        }
        pb_rising_edges >>= 1;
    }
    // printf("FINAL: 0x%x\r\n", grouped_relay_states);
    set_relays(addr, grouped_relay_states);
    return grouped_relay_states;
}

uint8_t pb_edge_detect(uint8_t current_state)
/*
 Push button (PB) rising edge detection.
 uint8_t argument contains 8 PB states (every 1 means PB was pressed).
 uint8_t return value contains the rising edgeds, compared to the former PB states.
 The former PB states are stored in local static variable with the inital value 0.
*/
{
    static uint8_t last_state = 0x00;
    uint8_t rising_edges = 0x00;
    rising_edges = current_state & ~last_state; // Get changes from last state
    last_state = current_state; // Store current state
//    if (rising_edges > 0)
//    {
//        printf("PB: 0x%x\r\n",rising_edges);
//    }
    return rising_edges;
    
}

uint8_t pb7_long_press_detect(uint8_t pb_states, uint8_t rising_edges)
/*
 Returns uint8_t value: 0 - nothing happend
                        1 - Short button press detected
                        2 - Long button press detected
 */
{
    static uint8_t button_pressed = 0;
    //printf("TMR0: 0x%x\r\n", TMR0_ReadTimer());
    // Start counter only at rising edges
    if ((rising_edges & PB_MASK.PB7) == PB_MASK.PB7)
    {
        TMR0_StartTimer();
        button_pressed = 1;
        return(1);
    }
    // Time limit for long press reached
    if (TMR0_HasOverflowOccured())
    {
        TMR0_StopTimer();
        TMR0_WriteTimer(0x00);
        PIR0bits.TMR0IF = 0;
        button_pressed = 0; // To avoid short button press at next function call
        return(2);
    }
    // PB released prematurely
    if ((button_pressed == 1) && (pb_states & PB_MASK.PB7) == 0x00)
    {
        TMR0_StopTimer();
        TMR0_WriteTimer(0x00);
        PIR0bits.TMR0IF = 0;
        button_pressed = 0;
        return(1);
    }
    
    return(0);
}

void pb7_led_flash()
{
    static uint8_t led_flash = 0;
    if (led_flash < 5)
    {
        set_pb_color(CH7_LED, COLOR_WHITE);
    }
    else
    {
        set_pb_color(CH7_LED, COLOR_OFF);
    }
    if (led_flash > 9)
    {
        led_flash = 0;
    }
    led_flash++;
}

void set_pb_groups(uint8_t *p_pb_groups, uint8_t pb_rising_egdges)
{
    // For each PB press, increment the respective push button group by one.
    for (uint8_t ii = 0; ii < PB_GROUPS; ii++)
    {
        if (pb_rising_egdges & 0x01)
        {
            // Increase group, reset to 0 after last group number
            p_pb_groups[ii] = (p_pb_groups[ii] + 1) % PB_GROUPS;
            printf("PB 0x%x: GROUP 0x%x\r\n", ii, p_pb_groups[ii]);
        }
        pb_rising_egdges >>= 1; // Right shift for next PB
    }
}

void calculate_pb_group_masks(uint8_t *p_pb_groups, uint8_t *p_pb_group_mask)
{
    // Loop over pb_group_mask
    for (uint8_t mask_idx = 0; mask_idx < PB_GROUPS; mask_idx++)
    {
        p_pb_group_mask[mask_idx] = 0x00; // Reset before update
        // Loop over pb_groups
        for (uint8_t group_idx = 0; group_idx < PB_GROUPS; group_idx++)
        {
            if (p_pb_groups[group_idx] == mask_idx)
            {
                p_pb_group_mask[mask_idx] |= 1 << PB_GROUPS; // Set MSB
            }
            p_pb_group_mask[mask_idx] >>= 1;
        }
        // printf("GROUP_MASK %x: 0x%x\r\n", mask_idx, p_pb_group_mask[mask_idx]);
    }
}
/**
 End of File
*/
